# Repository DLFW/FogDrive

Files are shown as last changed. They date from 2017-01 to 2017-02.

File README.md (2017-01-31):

Welcome to FogDrive
===================

The FogDrive project aims to provide free and open source electronics for vaping devices, the so called “mods”.
This includes the circuit specifications, parts lists, proposals on how to build the actual board
and – last but not least – the firmware for the micro-controller which is part of the circuit.

FogDrive is a free and open project, published under the [GNU General Public License](http://www.gnu.org/licenses/), version 3. We have no commercial interests and provide only information on how to build the electronics on your own.

FogDrive is under very early development. Mira is the first simple FogDrive that just switches the vaporizer on and off via a MOSFET.
The vaporizer is driven directly by the battery. In addition, Mira supports a few tiny comfort
features like battery voltage supervision. The next circuit is in an early planning phase.

Mira is currently in beta status and we are working on an online documentation and the host the the FogDrive builts.

For all of those out there who are interested to participate in the development: you are very welcome! Especially people who can contribute to the design of the voltage converters and electronic geeks in general could fill a significant gap. :) If you’re interested, please mail to `fogdrive {ät} llin -fullstop- info` or leave a message on the GitHub wiki.

* * *

FogDrive is a free and open project, you can redistribute it and/or modify
it under the terms of the [GNU General Public License](http://www.gnu.org/licenses/) as published by
the Free Software Foundation, either version 3 of the License, or any later version.

FogDrive is distributed in the hope that it will be useful,
but without any warranty; without even the implied warranty of
merchantability or fitness for a particular purpose.  See the
GNU General Public License for more details.

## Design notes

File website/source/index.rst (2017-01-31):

..  FogDrive (https://github.com/FogDrive/FogDrive)
    Copyright (C) 2016  Daniel Llin Ferrero

    This program, including it’s documenation and related circuit designs
    is free software: you can redistribute it and/or modify
    it under the terms of the GNU General Public License as published by
    the Free Software Foundation, either version 3 of the License, or
    any later version.

    This program is distributed in the hope that it will be useful,
    but WITHOUT ANY WARRANTY; without even the implied warranty of
    MERCHANTABILITY or FITNESS FOR A PARTICULAR PURPOSE.  See the
    GNU General Public License for more details.

    You should have received a copy of the GNU General Public License
    along with this program.  If not, see <http://www.gnu.org/licenses/>.

.. FogDrive documentation master file, created by
   sphinx-quickstart on Thu Sep 29 23:41:44 2016.

===================
Welcome to FogDrive
===================

The FogDrive project aims to provide free and open source electronics for vaping devices, the so called “mods”.
This includes the circuit specifications, parts lists, proposals on how to build the actual board
and – last but not least – the firmware for the micro-controller which is part of the circuit.

FogDrive is a free and open project, published under the `GNU General Public License`_, version 3.

.. toctree::
    :hidden:

    mira
    users
    developers

FogDrive is under early development. Currently, it provides one simple working circuit in beta status, namely :ref:`mira`.
Each of the (hopefully) multiple circuits the project will provide in the future is called “a FogDrive”.
So, Mira is the first FogDrive the FogDrive project provides. :)


    
Mira is the first simple FogDrive that just switches the vaporizer on and off via a MOSFET.
The vaporizer is driven directly by the battery. In addition, Mira supports a few tiny comfort
features like battery voltage supervision.


     
Well, there are two kind of stakeholders of FogDrive, the *Modder* who builds and uses a FogDrive to build an actual vape mod,
and the *Vapor*, the end user, who uses a mod with a FogDrive to vape. :) While the latter one might only be interested in some
background information (you’re welcome to browse this pages, of course!), the “User Documentation” here addresses the modder
who has to build a FogDrive.



You can also work on FogDrives sources, the circuits, the firmware or the documentation. You can do that to adapt the projects for your needs.
Since Mira for example does not have any possibility to get configured, the sources are the only way to – for example – change the four-time-click
for switching the device on and off into a triple click. Furthermore (and even better :)), you can help the project by contributing to the development.
Add some features or improve the circuits!
FogDrive could definitely need some help by some electronic geeks, micro-controller hackers
and even some modders who wants to figure out clever ways to integrate a FogDrive in self-build or reused mods.

FogDrive in the Web
===================

FogDrive is hosted on on `GitHub`_ at https://github.com/FogDrive/FogDrive.

If you have a GitHub account, feel free to use `Mira’s GitHub wiki`_ to get in contact.

.. _GitHub: http://github.com

.. _Mira’s GitHub wiki: https://github.com/FogDrive/FogDrive/wiki

Supporting FogDrive
===================

FogDrive needs support!
There are various ways to help the project. Using it and giving some feedback is the first one.
Constructive feedback and simply knowing that people are using or intrested in FogDrive will increase the motivation. :)

If you like the idea of FogDrive, you can support the Projekt also by making more people get to know about it.
Mention it in a forum, at your regulars’ table or wherever you think other people could be intrested.

Last but not least, you can help FogDrive by active participation. Get in contact via GitHub if you're intrested,
or simply fork the project on GitHub. Especially electronic geeks could fill a significant competency gap. ;)
For the long term goal of FogDrive – an up-to-date, fully regulated vaping circuit – it would be great to
have people in the team that can contribute to the design of the voltage converter. But also firmware
developers are welcome. Even if you would like to maintain the documentation or if you have an idea how enhance
the projects basics (maybe you have an idea about a bigger Wiki or on how to produce cheap PCBs), you are
welcome to get in contact! As for any hobbiest open source project, the projects stability depends on the team size.
And as long as this is mostly a one-man show, the future of the project is always in danger.

Future
======

Since Mira was just a simple “first shoot” to get the project running, the next FogDrive is already in the queue.
After clarifying some questions about the repository structure and the build process, the development of **Vega**
will start. As of now, the planned Features for the Vega FogDrive are:

* MOSFET switch and battery voltage supervision as for Mira
* Measurement of the vaporizer (coil) resistance
* Vaporizer voltage control (step down) via PWM
* Support for different user interfaces

The progress on Vega will highly depend on the private time that can be spend on this. Some support could increase 
the development speed. ;)

The great goal is a fully regulated control that can properly lower and increase the battery’s voltage without
the PWM ripples but with a mostly smooth output voltage. If this can be archived depends also on the available time
and support the project gets.

+----------------------------------------------------------------------------------------+
| FogDrive is a free and open project, you can redistribute it and/or modify             |
| it under the terms of the `GNU General Public License`_ as published by                |
| the Free Software Foundation, either version 3 of the License, or any later version.   |
|                                                                                        |
| FogDrive is distributed in the hope that it will be useful,                            |
| but without any warranty; without even the implied warranty of                         |
| merchantability or fitness for a particular purpose.  See the                          |
| GNU General Public License for more details.                                           |
+----------------------------------------------------------------------------------------+

.. _GNU General Public License: http://www.gnu.org/licenses/

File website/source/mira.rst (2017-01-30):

.. _mira:

====
Mira
====

Mira is the first simple FogDrive which just switches the vaporizer on and off and provides a voltage measurement.

It was mainly developed to get a grip on the topic and the basic technologies and to have a first simple
circuit that is small enough to fit into a 22mm tube, even when it’s build on a PCB with a
2.54 mm raster and “through-hole” parts (including a DIL package μC).

.. _`3D image`:

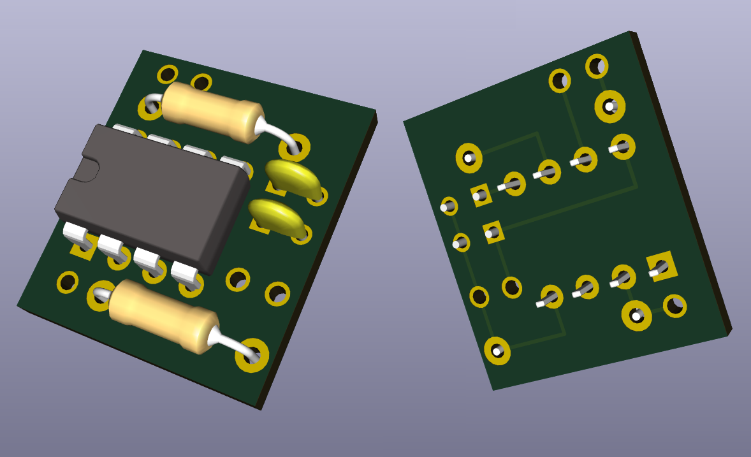
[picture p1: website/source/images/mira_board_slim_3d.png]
3D image of an example Mira board


   This is a 3D image of the front and back side of the example PCB layout for Mira. The board measures 16.5mm × 19mm
   and is designed with a 2.54 mm raster for “through-hole” parts (including a DIL package μC). This makes it easy to
   solder and makes it possible to use standard breadboard and stripboard PCBs.

Mira is in beta status. Some tiny enhancements might come up soon and it is going into the practical test phase.

Features
========

These are the basic features:

* Direct switching the battery voltage to the vaporizer (n-channel MOSFET, low-side, gate powered via the μC with the battery voltage)
* Simple user interface (UI), based on one button switch and one LED
* Switching on and off the device via a four-click (LED blinks)
* Battery supervision

  * LED stays off during vaping with battery voltage ≥ 3.5 V (under load)
  * LED lights up at battery voltage between 3.2 V and 3.5 V (under load)
  * LED blinks when battery voltage drops beneath 3.2 V (under load)
  * (Inhibiting firing at very low voltage to be implemented)
  
* Battery voltage display on double click (LED “blinks” the last measured battery voltage under load)

Parts
=====

Miras circuit consists of only a handfull of parts with a total cost of less than 7€, depending where you buy it, of course.
The parts are listed in the following table:

==========  ================= ====================================== ======
Reference   Part              Value/Type                             Number
==========  ================= ====================================== ======
IC1         Micro-controller  ATTiny45 P/PU                          1
R1          Resistor          15 KΩ                                  1
R2          Resistor          100 Ω                                  1
C1, C2      Capacitor         10nF                                   2
SW1         Push Button       normally open                          1
D1          LED               any low current (≤ 20mA)               1
Q1          MOSFET            IRLB3034 (n-channel, TTL power FET)    1
==========  ================= ====================================== ======

Beside the ATTiny45 (**IC1**), also the ATMega328 P/PU is supported but it’s unlikely that
somebody really wants to use that chip since it’s much bigger and even a little more expensive.
The chip is just supported because it was used during development.

The resistor can be any standard carbon resistor. Higher tolerances of 5% are no problem.
**R1** is used as a pull down resistor for the MOSFET to avoid occasional gate voltages and
to allow the MOSFET’s gate to discharge after firing has stopped. **R2** is simply used as a
current limitier for the LED **D1**. The value can changed to adapt the brightness of the LED. The only
restriction is to limit the LED current to 20mA when the LED-resitor series is powered with a
fully loaded battery (4,2 V).

**C1** just buffers the μC’s power supply while **C2** is requested by the μC’s datasheet for the way the battery voltage is measured.
It should not be a problem to take a little higher values for both.

The switch **SW1** must be a closing switch (normally open, n.o.), a switch which contacts are only closed when actuated.
In most applications, a push button will be used. It can be a very small button, it does not have to carry any significant current.

The LED **D1** is a standard low current LED which current has to be limited by **R2** as explained above. Any color and shape
can be used, of course.

The MOSFET **Q1** is the actual switch of the circuit. It connects and disconnects the vaporizer to the battery on the 
behalf of the μC. In principle, any n-channel power MOSFET can be used as long as a high drain current and a low gate
voltage is supported.

Circuit
=======

The circuit is not problematic at all. The basic roles of the particular parts are explained in the `Parts`_ section.
The connections are also not problematic since we have no high frequencies mostly low currents in general.
High currents are flowing only through these three connections:

* From the battery plus pole to the vaporizer
* From the battery minus to the MOSFETs Source
* From the MOSFETs Drain to the vaporizer

These conncetions must have a proper diameter and should be as short as possible.

.. _`Circuit Schema`:

You should also take care that the conncetion from the MOSFETs Gate through resistor **R1** 
to GND (Battery minus) is stable. It doesn't take a high current, so you can use even a very thin
connection, but the connection should never break. Otherwise, the vaporizer could be cathed in a
“contineous firing” where it's not possible to stop the fire without disconnection either the
vaporizer or the battery.

Higher frequencies are only present on the connection of the LED **D1** since the LED is controlled 
by a PWM which controls the LEDs brightness.

Firmware
========

Both targets, the AT Tiny 45 as well as the AT Mega 328 must run with 1 MHz by the internal clock.
This is the factory setting, so there is no need at all to change any fuse bits. The firmware can just be download to the μC as
it comes from the shop. The process of “flashing” (programming) the μC is explained at “:ref:`users_programming`” on the “Users” page.

Some background information for those who are intrested:
Mira’s firmware is the result of the some first experiments of programming a μC as well as the result of some incremental enhanced design approaches.
It was designed and refactored with the goal to have some fundamentals for the next circuit.
All in all, the firmware’s flash footprint is bigger than necessary, but small enough to fit on the planned minimum target,
the AT Tiny 45. Mira’s firmware needs ~4kByte (currently 4052 bytes) for the AT Tiny 45 P, and ~6kByte (currently 6202 bytes) for the AT Mega 328 P.
The AT Mega firmware is bigger because of some debug and development feature available for the UART connection which runs with 4800 baud.

Example PCB Arrangement
=======================

In most setups, the switch, the LED and the MOSFET (SW1, D1, Q1) will be mounted ouside of the PCB, directly connected the the mods housing.
The remaining parts are soldered on a PCB.

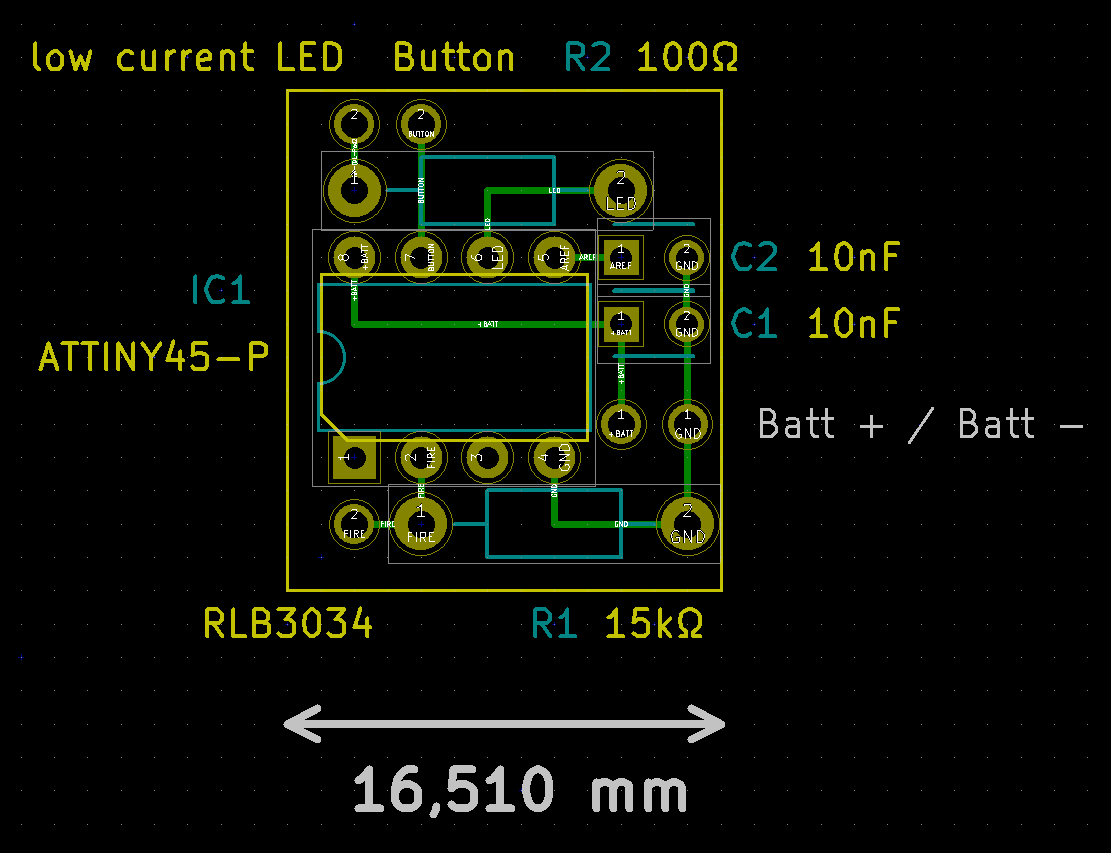
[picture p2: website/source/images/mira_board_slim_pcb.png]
CAD image of the example Mira board

   
   A concept view of the Mira example PCB. Top view.

The example PCB for Mira given here follows this approach. The PCB has a size of 16.5mm × 19mm.
It uses only standard “through-hole” parts and a standard 2.54 mm raster. This makes it possible to use “solder breadboards”
or stripboards. Everybody with a little bit of soldering experience and craftsmans skills should be able to build a Mira FogDrive.
The `3D image`_ on the top of this page gives an impression on how the parts are mounted on the front side and on how the
tracks are places on the back side. Also the `Circuit Schema`_ shown in the previous section should be checked when a Mira
FogDrive is build. For additional information, a CAD image (top view) and a track plot (bottom view) is shown in this section.

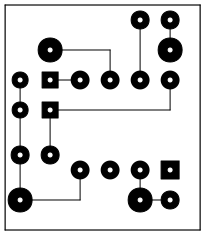
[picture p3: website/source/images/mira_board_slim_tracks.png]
schema image of an example Mira board

   
   The tracks of the Mira example PCB. Botton view.
   A `PDF version`_ as DIN A4 page can be used for
   a real scale print.

The track plot is also available as `PDF version`_. It is plotted on a DIN A4 sheet and should produce a scale correct printout
when printed with 100% scale and without borders. It can also be used to produce a real printed circuit board.
   
.. _`PDF Version`: _static/mira_board_slim_tracks.pdf

By changing some cable connections and maybe placing one or both resistors also outside of the PCB, it is possible to further shrink the size of the PCB.
Of course, with SMD parts even much smaller sizes can be archived. It is also possible to build the whole circuit in a  “flying”
construction, without any PCB but having the parts directly soldered together. This is absolutely possible with a small circuit like Mira.

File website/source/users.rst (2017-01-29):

.. _users:

=====
Users
=====

So, if you’re a *modder* and want to build a mod with :ref:`mira` (the only FogDrive at the moment), this
page is for you.

The basic workflow
==================

What you should keep in mind!
=============================
→ safety

Micro-controllers
=================

.. _users_programming:

Programming a micro-controller
==============================

So, :ref:`mira` uses a μC which has to be programmed with the firmware. The firmware is a single file with the
file name suffix ``hex``. This kind of firmware is directly written to the flash. Many small devices nowadays that are running
on a μC use a bootloader. If a bootloader is “flashed” as basic firmware, the actual program can then be downloaded to
the μC by the help of a convienient PC application e.g. via a USB connection.

Mira does not support such a booloader and as of now, a bootloader feature has quite a low priority in the FogDrive development.
As a result, the firmware must be programmed via one of the μCs native interfaces.

Building the board
==================

License
=======

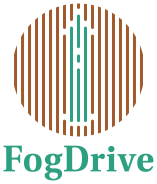
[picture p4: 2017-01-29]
website/source/images/fogdrive.png

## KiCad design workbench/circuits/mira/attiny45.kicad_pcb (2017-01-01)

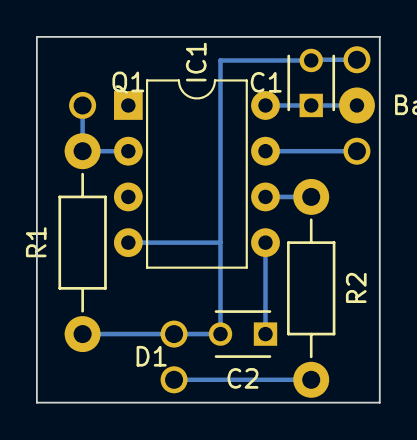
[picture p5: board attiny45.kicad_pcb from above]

Board: 2 copper layers, 19.0 x 20.3 mm, 8 parts (0 on the bottom side), 6 nets.

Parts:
Bat+: SolderWirePad_single_0-8mmDrill
C1, C2: 10nF; C_Disc_D3_P2.5
D1: low current LED; WireConnection_1.50mmDrill
IC1: ATTINY45-P; DIP-8_W7.62mm
Q1: RLB3034; WireConnection_1.50mmDrill
R1: 22kΩ; Resistor_Horizontal_RM10mm
R2: 100Ω; Resistor_Horizontal_RM10mm

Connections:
+BATT: C1.1, IC1.8
/Mira/AREF: C2.1, IC1.5
/Mira/FIRE: IC1.2, Q1.2, R1.1
/Mira/LED: IC1.6, R2.2
GND: C1.2, C2.2, D1.1, IC1.4, R1.2
unnamed: D1.2, R2.1

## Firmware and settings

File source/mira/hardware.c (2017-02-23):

/*
    FogDrive (https://github.com/FogDrive/FogDrive)
    Copyright (C) 2016  Daniel Llin Ferrero

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
    You should have received a copy of the GNU General Public License
    along with this program.  If not, see <http://www.gnu.org/licenses/>.
*/

#include <avr/io.h>

#include "logic.h"
#include "hardware.h"
#include "queue.h"
#include MCUHEADER
#ifdef UART_ENABLED
    #include "deviface.h"
#endif

#define CTRLMAP_FIRE_BIT_MASK   (1 << HWMAP_HW_FIRE_BIT_IX)
#define ALL_OUT_BITS            CTRLMAP_FIRE_BIT_MASK


// state machine: battery voltage measurement (bvm)
#define SMS_BVM_IDLE 0
#define SMS_BVM_START_MEASUREMENT 1
#define SMS_BVM_MEASURING 3
#define SMS_BVM_CALCULATING 4
uint8_t sm_bvm_status = SMS_BVM_IDLE;

uint8_t make_measurement = 0;

#define AVR_INTERNAL_REFERENCE_VOLTAGE 1100000L     // in 10^(-6) V
#define BVM_SMOOTHING 4
uint16_t battery_voltage_sum = 0;
uint8_t battery_voltage_values_ix = 0;

Queue hw_event_queue;
QueueElement hw_event_queue_elements[5];


uint8_t hardware_init(void) {
    // configure the fire pin as output by setting the related direction bit to 1
    HWMAP_HW_FIRE_DDR |= CTRLMAP_FIRE_BIT_MASK;
    // initialize the fire pin with 0 (fire off)
    HWMAP_HW_FIRE_PORT &= ~CTRLMAP_FIRE_BIT_MASK;
    // set up the hardware event queue
    queue_initialize(&hw_event_queue, 5, hw_event_queue_elements);
    // enable the ADC which uses V_CC as reference and the constant voltage V_GB as input
    mcu__enabled_one_adc_with_vcc_reference_and_vgb_input();

    return 0;
}

void hardware_fire_on(void) {
    #ifdef UART_ENABLED
    deviface_putline(">Fire On");
    #endif
    HWMAP_HW_FIRE_PORT = HWMAP_HW_FIRE_PORT | CTRLMAP_FIRE_BIT_MASK;
    QueueElement* e = queue_get_write_element(&hw_event_queue);
    e->bytes.a = HW__FIRE_ON;
}

void hardware_fire_off(void) {
    #ifdef UART_ENABLED
    deviface_putline(">Fire Off");
    #endif
    HWMAP_HW_FIRE_PORT = HWMAP_HW_FIRE_PORT & ~CTRLMAP_FIRE_BIT_MASK;
    QueueElement* e = queue_get_write_element(&hw_event_queue);
    e->bytes.a = HW__FIRE_OFF;
}

void hardware_power_down() {
    sm_bvm_status = SMS_BVM_IDLE;       // stop the battery voltage measure in case it's running
    queue_clear(&hw_event_queue);        // clear unprocessed events if there are some
}

void hardware_power_up() {
    // nothing to do
}

void sm_bvm(void) {
    switch (sm_bvm_status) {
        case SMS_BVM_IDLE: {
            if (make_measurement == 1) {
                MCU__START_SINGLE_ADC_CONVERSION;
                battery_voltage_values_ix = 0;
                sm_bvm_status = SMS_BVM_MEASURING;
                make_measurement = 0;
                battery_voltage_sum = 0;
            }
            break;
        }
        case SMS_BVM_MEASURING: {
            if (MCU__SINGLE_ADC_CONVERSION_IS_DONE) {
                // measurement done
                uint8_t adc_low = ADCL;     // get the low byte of the measured value
                uint8_t adc_high = ADCH;    // get the high byte of the measured value
                uint16_t adc_result = (adc_high<<8) | adc_low; //put the 16 bit measurement result together
                uint16_t vcc =  AVR_INTERNAL_REFERENCE_VOLTAGE / adc_result;   //turn the raw adc value into milli volt
                battery_voltage_sum += vcc;
                if (++battery_voltage_values_ix == BVM_SMOOTHING) {
                    sm_bvm_status = SMS_BVM_CALCULATING;
                } else {
                   MCU__START_SINGLE_ADC_CONVERSION;            // start another measurement, stay in this state...
                }
            }
            break;
        }
        case SMS_BVM_CALCULATING: {
            // and put the final result into the event queue
            QueueElement* e = queue_get_write_element(&hw_event_queue);
            e->bytes.a = HW__BATTERY_MEASURE;
            e->bytes.b = (uint8_t) (battery_voltage_sum / (BVM_SMOOTHING * 100));
            // go back to the idle state to wait for the next measurement instruction
            sm_bvm_status = SMS_BVM_IDLE;
            break;
        }
    }
}

void hardware_step(void) {
    if (~ global_state && GS_AWAKENING) {
        // if the device is not jus awakening (but really switched on)
        sm_bvm();
    }
}

void do_battery_measurement(void) {
    make_measurement = 1;
}

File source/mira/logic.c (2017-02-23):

/*
    FogDrive (https://github.com/FogDrive/FogDrive)
    Copyright (C) 2016  Daniel Llin Ferrero

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
    You should have received a copy of the GNU General Public License
    along with this program.  If not, see <http://www.gnu.org/licenses/>.
*/

#include <avr/io.h>
#include <util/delay.h>
#include "logic.h"
#include "hardware.h"
#include "ui.h"
#include MCUHEADER
#ifdef UART_ENABLED
    #include "deviface.h"
#endif


/*
 * Global variables
 */
static uint8_t local_bools = 0;
#define LB_HW_IS_FIRING   1     // if true, hardware is currently firing
#define LB_PRINT_BVMS     2     // if true, the battery voltage is printed each time its received (set via deviface)

uint8_t battery_voltage_under_load = 0; //external
uint8_t global_state = GS_ON;           //external

void logic_loop (void) {
    static uint16_t logic_main_cycle_counter = 0;           // contineously counts the cycles of the main loop and just overflows at its value range end back to 0
    #ifdef UART_ENABLED
    static uint16_t last_logic_cycle_value = 0;             // stores the logic cycle count at each 50 ms event and is used to calc the delta
    static uint16_t last_logic_cycles_per_50ms_event = 0;   // stores the number of cycles that happened between the two last 50ms events
    static uint16_t min_logic_cycles_per_50ms_event = 0;    // stores the minimum value of the above variable throughout the whole uptime
    #endif
    static uint8_t pulse_counter_for_battery_voltage_measurement = 0;   // counts 50ms events to trigger battery voltage measurements in regular intervals


    #ifdef UART_ENABLED
    deviface_putline("FogDrive  Copyright (C) 2016, the FogDrive Project");
    deviface_putline("This program is free software and comes with ABSOLUTELY NO WARRANTY.");
    deviface_putline("It is licensed under the GPLv3 (see <http://www.gnu.org/licenses/#GPL>).");
    deviface_putline("\r\nHi! This is the Mira FogDrive.\r\n");
    #endif

    // lets enter the main loop

    while(1) {
        ui_input_step();    // the user interface gets its cycle
        hardware_step();    // the hardware gets its cycle

        if (global_state == GS_AWAKENING) {
            // If the device is "waking up"...
            // (Means, an interrupt has stopped the power down mode but we have not received a switch-on command from the UI yet.)
            QueueElement* e = queue_get_read_element(&ui_event_queue);
            // We just check for the very next UI event that is coming...
            if (e != 0) {
                if (e->bytes.a == UI__SWITCH_ON) {
                    // user asked to switch on the device again... we wake up
                    hardware_power_up();
                    ui_power_up();
                    global_state = GS_ON;
                    #ifdef UART_ENABLED
                    deviface_putline("DEVICE UP");
                    #endif
                } else if(e->bytes.a == UI__ABORT_AWAKENING) {
                    // no switch-on action by the user, the device goes to sleep again
                    #ifdef UART_ENABLED
                    deviface_putline("DOWN AGAIN");
                    #endif
                    mcu_power_down_till_pin_change(); // go to sleep
                }
            }
        }
        else
        {
            // The device on (not awakening)
            // process UI event
            QueueElement* e = queue_get_read_element(&ui_event_queue);
            if (e != 0) {
                if (e->bytes.a == UI__FIRE_BUTTON_PRESSED) {
                    hardware_fire_on();
                }
                if (e->bytes.a == UI__FIRE_BUTTON_RELEASED) {
                    hardware_fire_off();
                }
                if (e->bytes.a == UI__SWITCH_OFF) {
                    #ifdef UART_ENABLED
                    deviface_putline("DOWN");
                    #endif
                    hardware_fire_off();
                    hardware_power_down();
                    ui_power_down();
                    mcu_power_down_till_pin_change(); // go to sleep
                    global_state = GS_AWAKENING;
                    continue;
                }
                if (e->bytes.a == UI__50MS_PULSE) {
                    // 1) do the main cycle time measurement (for development purposes only)
                    #ifdef UART_ENABLED
                    if (last_logic_cycle_value < logic_main_cycle_counter) {
                        // no overflow
                        last_logic_cycles_per_50ms_event = logic_main_cycle_counter - last_logic_cycle_value;
                        if (min_logic_cycles_per_50ms_event > last_logic_cycles_per_50ms_event) {
                            min_logic_cycles_per_50ms_event = last_logic_cycles_per_50ms_event;
                        }
                    }
                    last_logic_cycle_value = logic_main_cycle_counter;
                    #endif

                    // 2) trigger cyclical battery voltage measurement
                    if (local_bools & LB_HW_IS_FIRING) {
                        if (pulse_counter_for_battery_voltage_measurement > 3) {   // every 200ms (4*50ms) when the mod is firing
                            do_battery_measurement();
                            pulse_counter_for_battery_voltage_measurement = 0;
                        }
                    }
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

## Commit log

2016-09-30 Wrote a first intro text for the doc and added a simple backlog for the first significant steps. The logo is added as png file which will be removed later when the build chain is set up properly sinc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
2016-12-05 Added the first fogdrive sources from a private SVN repo.
    The first FogDrive, Mira, is under development.
    So far, it has a debounced switch which is directly used to activate/decative the vaporizer.
    The basic architecture ideas are in place and the preconditions of building it for multiple
    architecture should also be there. The build system is set up with SCons. A simple framework
    for variant management is implemented.
    The main focus now is on battery voltage measurement, a more sophisticated LED control and
    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
2016-12-05 * Implemented very rough battery voltage measurement * Enhanced deviface a little (removed info method, added a put method for uint16)
2016-12-09 Did a little refactoring and started with a PWM control for the LED(s). It doesn't really work at the moment. The LED flicers and the brigthness value has a very unexpected effect. What I will do nex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
    [atmega328p.c, atmega328p.h, deviface.c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]
2016-12-12 Refactoring UI timer
    Changed the timer used for the 10ms ISR to timer 2. Deactivated the old LED PWM approach.
    Furthermore I added a 8MHz variant of Mira in the SConstruct.
2016-12-13 HW PWM Experiment A HW PWM is working (T0A). It is just demonstarted by cyclically increasing the brightness. A first deviface command has been introduce to force the brightness.
2016-12-16 LED control
    LED control is under development. The basic HE PWM and the modularization of the LED logic work.
    Some small refactorings.
2016-12-16 LED modularization
    Moved initialization of LED PWM stuff into led module. Little cleanup.
2016-12-17 LED PWM changed to inverted mode The HW PWM for the LED is changed to inverted mode go be able to get the LED fully off.
    [atmega328p.c, led.c]
2016-12-17 Button logic module added Added a basic button module which detects press, release and multi-click events. It's not integrated into the UI so far.
2016-12-17 Button logic for fireing Integrated the button logic into the UI: The fire is switched on now when the button is pressed, but not clicked
2016-12-18 Started to implement a smart LED control
2016-12-19 Enhanced LED dimming (better value table) and added LED debug command
2016-12-19 Enhanced LED control
    The LED module was enhanced to be able to "play" small "light programs".
2016-12-19 LED control: fix and application
    Fixed an error in the linear dim command, used the first programs in the ui module.
    The linear dim function doesn't work well. Dimming down doesn't work at all and dimming up hasn't a good value sequence.
    [led.c, ui.c]
2016-12-20 LED control fix
    Fixed the linear dim command of the led module, added a UART put method for int8_t
    [deviface.c, led.c, ui.c]
2016-12-20 Battery voltage measurement: added smoothing
    The voltage measurement for the battery takes four separate measurements now, throws the lowest and the highest value and calculates the avverage for the two median values.
2016-12-21 Integrated battery voltage into UI, Code-Cleanup
    The battery voltage measurement is triggered cyclically now.
    The UI lights up the LED now when the voltage drops below a magic value (3,4 V).
    Added some deviface commands.
2016-12-22 Declared a few variables static
    Declared the local variables of the UI and the logic module as static to avoid global linkage conflicts.
    [logic.c, ui.c]
2016-12-25 Added first circuit schematics
    [atmega328p.sch, mira.sch]
2017-01-01 Added first schematic artifacts for the tiny 45 port of Mira.
    [attiny45.kicad_pcb, attiny45.sch, mira.sch]
2017-01-05 added a 2nd stage of battery voltage warning (blinking for very low voltage)
2017-01-06 Reworked the build setup to support multiple MCUs for a FogDrive.
    [atmega328p.c, atmega328p.h]
2017-01-06 Ported Mira to Tiny45... ...but the binary is too big for the tiny's flash and untested. So, the built hex file is not usable at the moment.
    [attiny45.c, attiny45.h, deviface.c]
2017-01-06 Reduced flash size of Mira for the Tiny The needed size of flash memory was reduced by excluding deviface (UART) related code by the preprocessor. The preprocessor checks wether "UART_ENABLED" is def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
2017-01-06 Various fixes, Tiny45 port done * Fixed a bug of the atmega328p module, introduced while doing the Tiny port * Fixed a bug in the attiny45 module (wrong PWM channel) * Fixed a deviface command: strin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
    [atmega328p.h, attiny45.c, attiny45.h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]
2017-01-06 Fixed a bug in the LED module and fine tuned the UI output
    [deviface.c, led.c, logic.c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]
2017-01-08 Added display of battery voltage (last load measurement) on double click
2017-01-15 added PCB laybout for Mira with AT Tiny 45
    [attiny45_slim.kicad_pcb]
2017-01-15 Simple implementation of power down works for the Mega328
2017-01-15 Power down feature in progress Moved power down responsibility to logic module. Added proper down methods for the UI and the hardware modules. Added clear function for queues.
2017-01-21 Implemented first working version of switching-on-off feature. The switch-off action doesn't have a working led program (aborted by the UIs power off function). Also started with a very few lines of 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
    [hardware.c, logic.c, logic.h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]
2017-01-21 Switch-on-off feature implemented for the Tiny45, reactivated build for Tiny45. Also changed some UI behavior (LED programs) to save some program memory. It's very tight for the Tiny45 now.
    [attiny45.c, deviface.c, hardware.c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]
2017-01-22 Added some simple button graphics for the docs.
2017-01-29 Cleaned up the Mira KiCad files... ... and moved them to an approproate subdirectory. Added the Mira "slim" PCB. Removed an old Sphinx page and moved the Sphinx project logo.
    [atmega328p.sch, attiny45.kicad_pcb, attiny45.sch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]
2017-01-31 Updated README.md (current status)
2017-02-19 Enhanced LED programs and flash footprint a bit
2017-02-19 Added callback command to the LED module, implemented proper LED programs for switching on and off
2017-02-19 Added auto-switch-off on very low battery voltage (2.9V) with LED blinking
2017-02-23 Added timeout feature for the button module
2017-02-23 Reducing flash footprint in progress (voltage measurement currently broken!)
    [hardware.c, logic.c]
2017-02-23 Voltage measurement works again with smaller flash footprint (removed median calculation - but that doesn't harm the measurement)
    [hardware.c]
2017-02-23 Removed deprecated stuff of the removed unstressed voltage measurement
2017-02-23 UI rework: on/off by 3-click, on-indicator on 1-click, reaction on timeout, LED dim-up on button release after timeout
    [ui.c]
